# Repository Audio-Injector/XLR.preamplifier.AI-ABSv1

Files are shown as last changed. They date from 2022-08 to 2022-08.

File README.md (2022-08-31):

XLR preamplifier

A balanced preamplifier based on the Audio Injector Analogue Breakout Standard v1 (AI-ABS v1)

https://github.com/Audio-Injector/AudioInjector-Analogue-Breakout-Standard

https://www.audioinjector.net/xlr-preamp

https://shop.audioinjector.net/detail/Sound_Cards/Balanced+XLR+preamplifier

Check the single ended (RCA) preamplifier here : https://github.com/Audio-Injector/RCA.preamplifier.AI-ABSv1

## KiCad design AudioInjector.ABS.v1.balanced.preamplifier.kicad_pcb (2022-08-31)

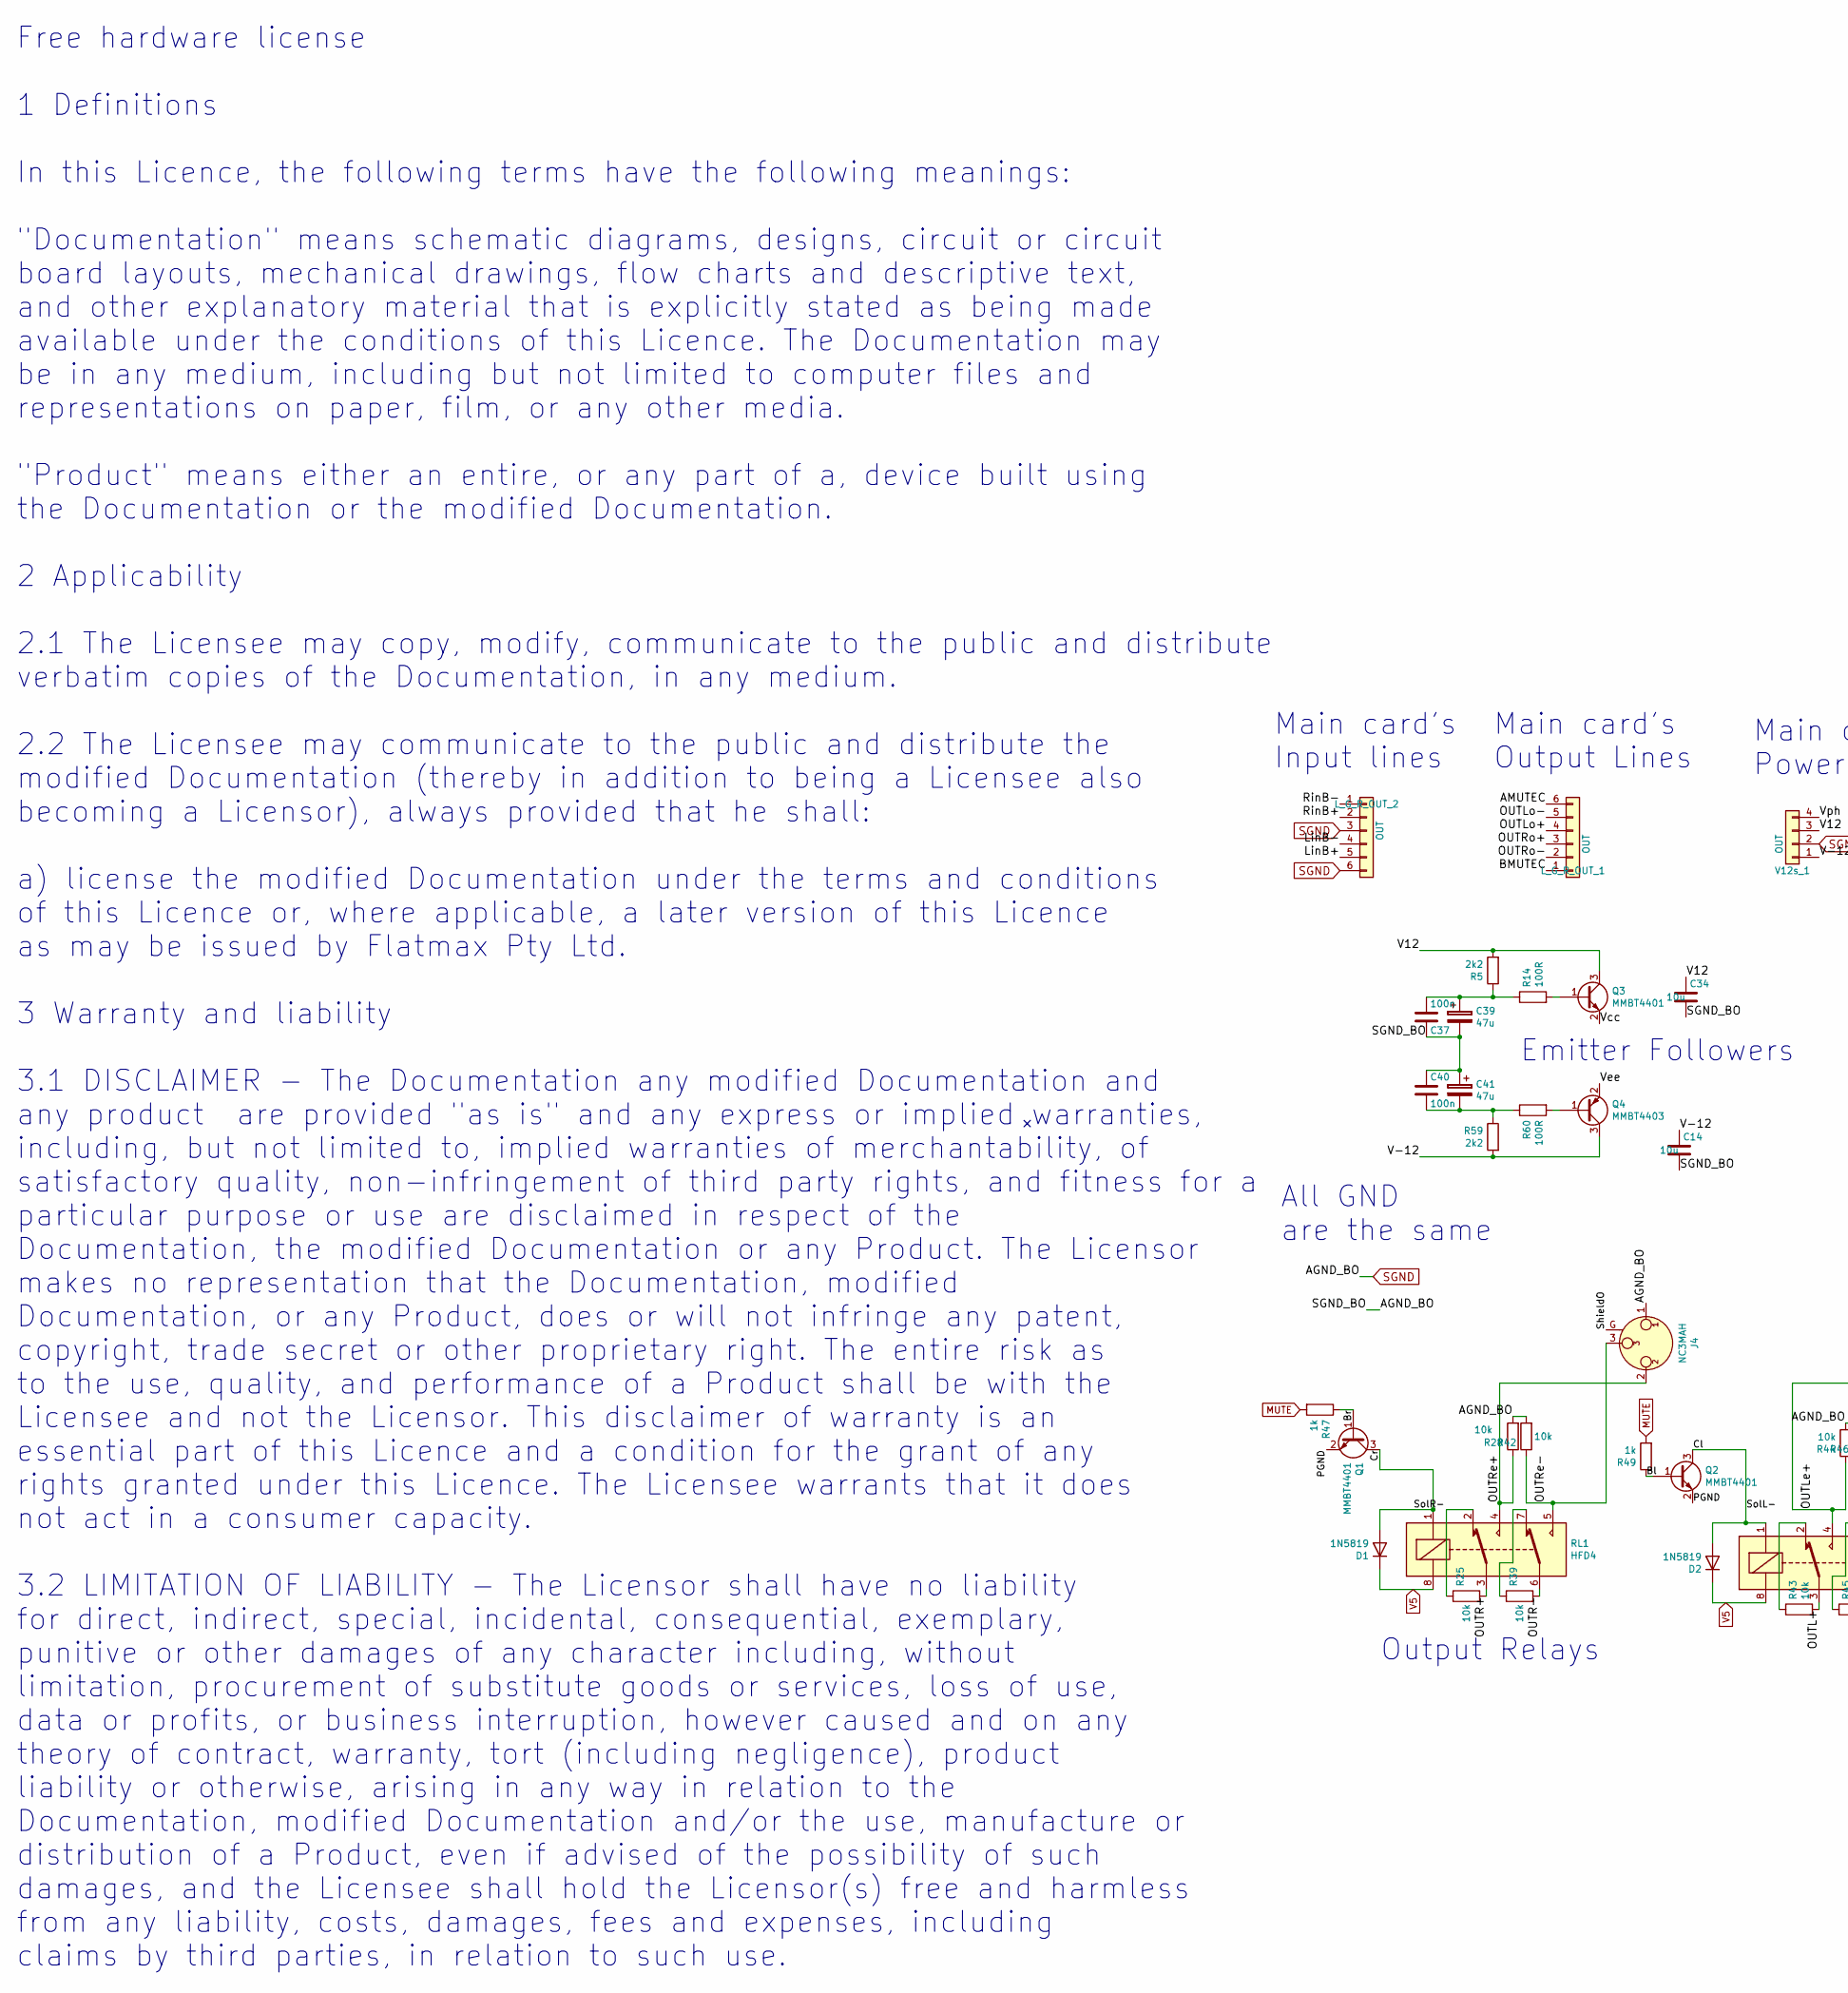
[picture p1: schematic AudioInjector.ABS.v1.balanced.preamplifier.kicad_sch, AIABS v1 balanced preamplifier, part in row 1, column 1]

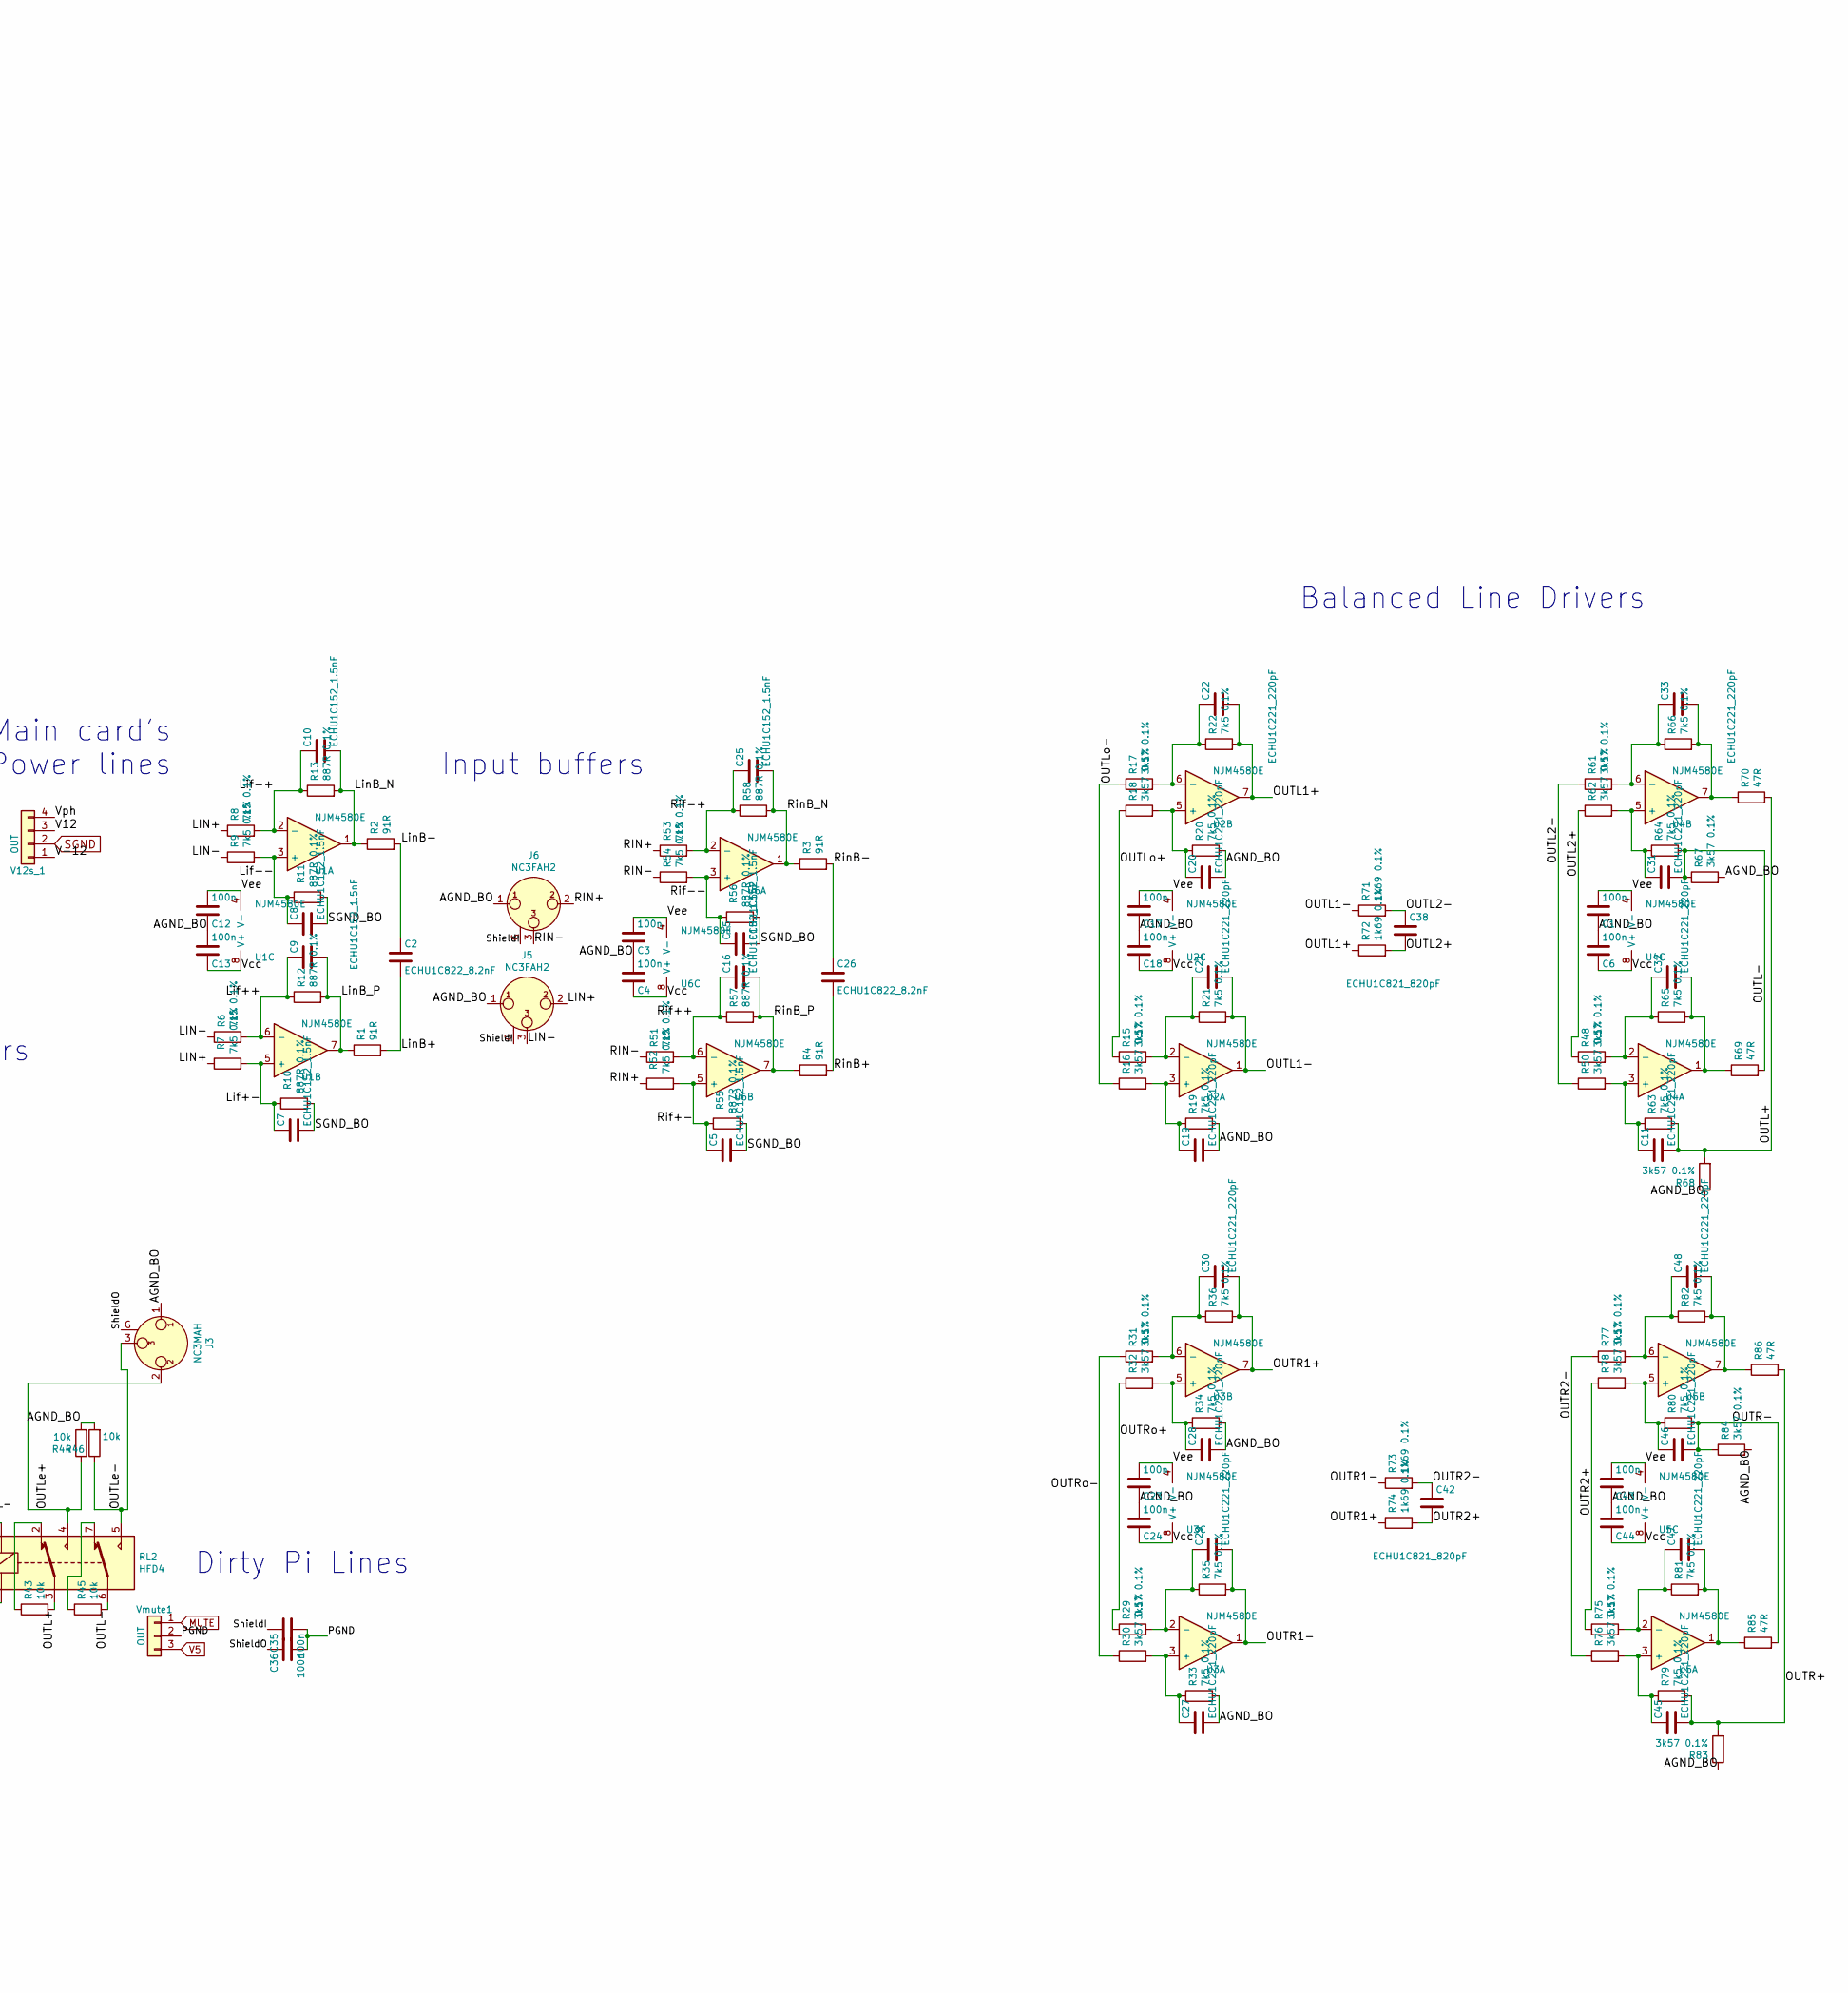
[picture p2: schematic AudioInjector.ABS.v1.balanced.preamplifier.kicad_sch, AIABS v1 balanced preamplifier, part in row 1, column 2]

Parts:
C1, C3, C4, C6, C12, C13, C17, C18, C23, C24, C35, C36, C37, C40, C43, C44: 100n; C_0603_1608Metric
C2, C26: ECHU1C822_8.2nF; C_0805_2012Metric
C5, C7, C8, C9, C10, C15, C16, C25: ECHU1C152_1.5nF; C_0805_2012Metric
C11, C19, C20, C21, C22, C27, C28, C29, C30, C31, C32, C33, C45, C46, C47, C48: ECHU1C221_220pF; C_0805_2012Metric
C14, C34: 10u; C_0805_2012Metric
C38, C42: ECHU1C821_820pF; C_0805_2012Metric
C39, C41: 47u; CP_Elec_6.3x7.7
D1, D2: 1N5819; D_SOD-123
J3, J4: NC3MAH; Jack_XLR_Neutrik_NC3MAH-0_Horizontal
J5, J6: NC3FAH2; Jack_XLR_Neutrik_NC3FAH2_Horizontal
L_G_R_OUT_1, L_G_R_OUT_2: OUT; PinHeader_1x06_P2.54mm_Vertical
Q1, Q2, Q3: MMBT4401; SOT-23
Q4: MMBT4403; SOT-23
R1, R2, R3, R4: 91R; R_0603_1608Metric
R5, R59: 2k2; R_0603_1608Metric
R6, R7, R8, R9, R19, R20, R21, R22, R33, R34, R35, R36, R51, R52, R53, R54, R63, R64, R65, R66, R79, R80, R81, R82: 7k5 0.1%; R_0603_1608Metric
R10, R11, R12, R13, R55, R56, R57, R58: 887R 0.1%; R_0603_1608Metric
R14, R60: 100R; R_0603_1608Metric
R15, R16, R17, R18, R29, R30, R31, R32, R48, R50, R61, R62, R67, R68, R75, R76, R77, R78, R83, R84: 3k57 0.1%; R_0603_1608Metric
R25, R28, R39, R42, R43, R44, R45, R46: 10k; R_0603_1608Metric
R47, R49: 1k; R_0603_1608Metric
R69, R70, R85, R86: 47R; R_0603_1608Metric
R71, R72, R73, R74: 1k69 0.1%; R_0603_1608Metric
RL1, RL2: HFD4; HDF4
U1, U2, U3, U4, U5, U6: NJM4580E; SOIC-8_3.9x4.9mm_P1.27mm
V12s_1: OUT; PinHeader_1x04_P2.54mm_Vertical
Vmute1: OUT; PinHeader_1x03_P2.54mm_Vertical

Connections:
/AMUTEC: L_G_R_OUT_1.6
/BMUTEC: L_G_R_OUT_1.1
/Bl: Q2.1 (B), R49.1
/Br: Q1.1 (B), R47.1
/Cl: D2.2 (A), Q2.3 (C), RL2.1
/Cr: D1.2 (A), Q1.3 (C), RL1.1
/LIN+: J5.2, R7.1, R8.1
/LIN-: J5.3, R6.1, R9.1
/Lif++: C9.1, R6.2, R12.1, U1.6 (-)
/Lif+-: C7.1, R7.2, R10.1, U1.5 (+)
/Lif-+: C10.1, R8.2, R13.1, U1.2 (-)
/Lif--: C8.1, R9.2, R11.1, U1.3 (+)
/LinB+: C2.2, L_G_R_OUT_2.5, R1.2
/LinB-: C2.1, L_G_R_OUT_2.4, R2.2
/LinB_N: C10.2, R2.1, R13.2, U1.1
/LinB_P: C9.2, R1.1, R12.2, U1.7
/OUTL1+: C22.2, R22.2, R72.1, U2.7
/OUTL1-: C21.2, R21.2, R71.1, U2.1
/OUTL2+: C38.2, R48.1, R62.1, R72.2
/OUTL2-: C38.1, R50.1, R61.1, R71.2
/OUTL+: C11.2, R43.2, R63.2, R68.2, R70.2, RL2.3
/OUTL-: C31.2, R45.2, R64.2, R67.1, R69.2, RL2.6
/OUTLe+: J3.2, R44.1, RL2.4
/OUTLe-: J3.3, R46.1, RL2.5
/OUTLo+: L_G_R_OUT_1.4, R15.1, R18.1
/OUTLo-: L_G_R_OUT_1.5, R16.1, R17.1
/OUTR1+: C30.2, R36.2, R74.1, U3.7
/OUTR1-: C29.2, R35.2, R73.1, U3.1
/OUTR2+: C42.2, R74.2, R75.1, R78.1
/OUTR2-: C42.1, R73.2, R76.1, R77.1
/OUTR+: C45.2, R25.2, R79.2, R83.2, R86.2, RL1.3
/OUTR-: C46.2, R39.2, R80.2, R84.1, R85.2, RL1.6
/OUTRe+: J4.2, R28.1, RL1.4
/OUTRe-: J4.3, R42.1, RL1.5
/OUTRo+: L_G_R_OUT_1.3, R29.1, R32.1
/OUTRo-: L_G_R_OUT_1.2, R30.1, R31.1
/PGND: C35.2, C36.2, Q1.2 (E), Q2.2 (E), Vmute1.2
/RIN+: J6.2, R52.1, R53.1
/RIN-: J6.3, R51.1, R54.1
/Rif++: C16.1, R51.2, R57.1, U6.6 (-)
/Rif+-: C5.1, R52.2, R55.1, U6.5 (+)
/Rif-+: C25.1, R53.2, R58.1, U6.2 (-)
/Rif--: C15.1, R54.2, R56.1, U6.3 (+)
/RinB+: C26.2, L_G_R_OUT_2.2, R4.2
/RinB-: C26.1, L_G_R_OUT_2.1, R3.2
/RinB_N: C25.2, R3.1, R58.2, U6.1
/RinB_P: C16.2, R4.1, R57.2, U6.7
/ShieldI: C35.1, J5.G, J6.G
/ShieldO: C36.1, J3.G, J4.G
/V12: C34.1, Q3.3 (C), R5.2, V12s_1.3
/V-12: C14.1, Q4.3 (C), R59.2, V12s_1.1
/Vcc: C4.1, C6.1, C13.1, C18.1, C24.1, C44.1, Q3.2 (E), U1.8 (V+), U2.8 (V+), U3.8 (V+), U4.8 (V+), U5.8 (V+), U6.8 (V+)
/Vee: C1.2, C3.2, C12.2, C17.2, C23.2, C43.2, Q4.2 (E), U1.4 (V-), U2.4 (V-), U3.4 (V-), U4.4 (V-), U5.4 (V-), U6.4 (V-)
/Vph: V12s_1.4
MUTE: R47.2, R49.2, Vmute1.1
unnamed: C11.1, R50.2, R63.1, U4.3 (+)
unnamed: C19.1, R16.2, R19.1, U2.3 (+)
unnamed: C20.1, R18.2, R20.1, U2.5 (+)
unnamed: C21.1, R15.2, R21.1, U2.2 (-)
unnamed: C22.1, R17.2, R22.1, U2.6 (-)
unnamed: C27.1, R30.2, R33.1, U3.3 (+)
unnamed: C28.1, R32.2, R34.1, U3.5 (+)
unnamed: C29.1, R29.2, R35.1, U3.2 (-)
unnamed: C30.1, R31.2, R36.1, U3.6 (-)
unnamed: C31.1, R62.2, R64.1, U4.5 (+)
unnamed: C32.1, R48.2, R65.1, U4.2 (-)
unnamed: C32.2, R65.2, R69.1, U4.1
unnamed: C33.1, R61.2, R66.1, U4.6 (-)
unnamed: C33.2, R66.2, R70.1, U4.7
unnamed: C37.2, C39.1, R5.1, R14.1
unnamed: C40.2, C41.2, R59.1, R60.1
unnamed: C45.1, R76.2, R79.1, U5.3 (+)
unnamed: C46.1, R78.2, R80.1, U5.5 (+)
unnamed: C47.1, R75.2, R81.1, U5.2 (-)
unnamed: C47.2, R81.2, R85.1, U5.1
unnamed: C48.1, R77.2, R82.1, U5.6 (-)
unnamed: C48.2, R82.2, R86.1, U5.7
unnamed: Q3.1 (B), R14.2
unnamed: Q4.1 (B), R60.2
unnamed: R25.1, RL1.2
unnamed: R39.1, RL1.7
unnamed: R43.1, RL2.2
unnamed: R45.1, RL2.7
SGND: C1.1, C3.1, C4.2, C5.2, C6.2, C7.2, C8.2, C12.1, C13.2, C14.2, C15.2, C17.1, C18.2, C19.2, C20.2, C23.1, C24.2, C27.2, C28.2, C34.2, C37.1, C39.2, C40.1, C41.1, C43.1, C44.2, J3.1, J4.1, J5.1, J6.1, L_G_R_OUT_2.3, L_G_R_OUT_2.6, R10.2, R11.2, R19.2, R20.2, R28.2, R33.2, R34.2, R42.2, R44.2, R46.2, R55.2, R56.2, R67.2, R68.1, R83.1, R84.2, V12s_1.2
V5: D1.1 (K), D2.1 (K), RL1.8, RL2.8, Vmute1.3

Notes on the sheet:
All GND are the same
Input buffers
Free hardware license 1 Definitions In this Licence, the following terms have the following meanings: "Documentation" means schematic diagrams, designs, circuit or circuit board layouts, mechanical drawings, flow charts and descriptive text, and other explanatory material that is explicitly stated 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
Output Relays
Dirty Pi Lines
Main card's Output Lines
Main card's Input lines
Balanced Line Drivers
Main card's Power lines
Emitter Followers

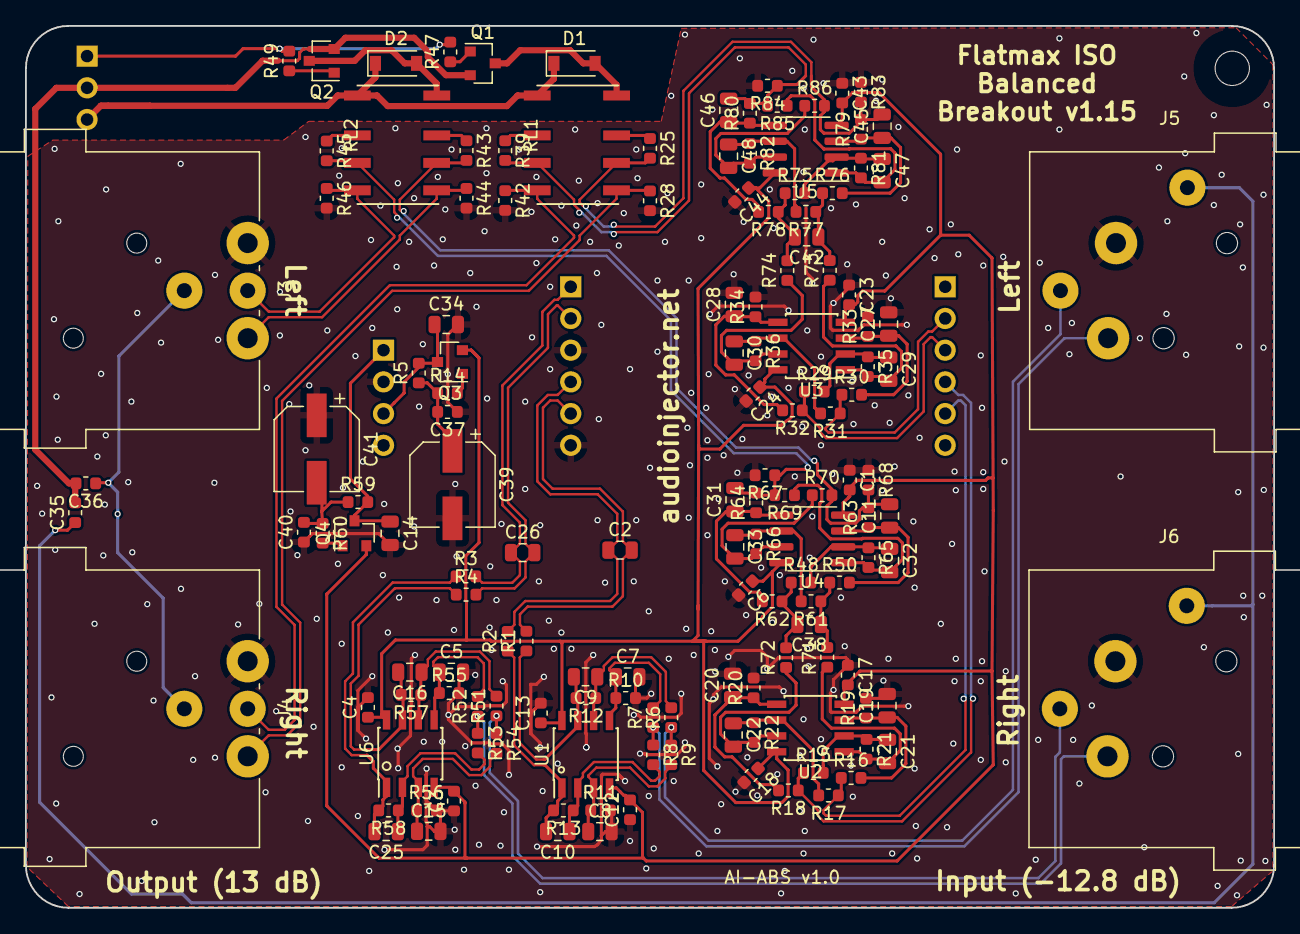
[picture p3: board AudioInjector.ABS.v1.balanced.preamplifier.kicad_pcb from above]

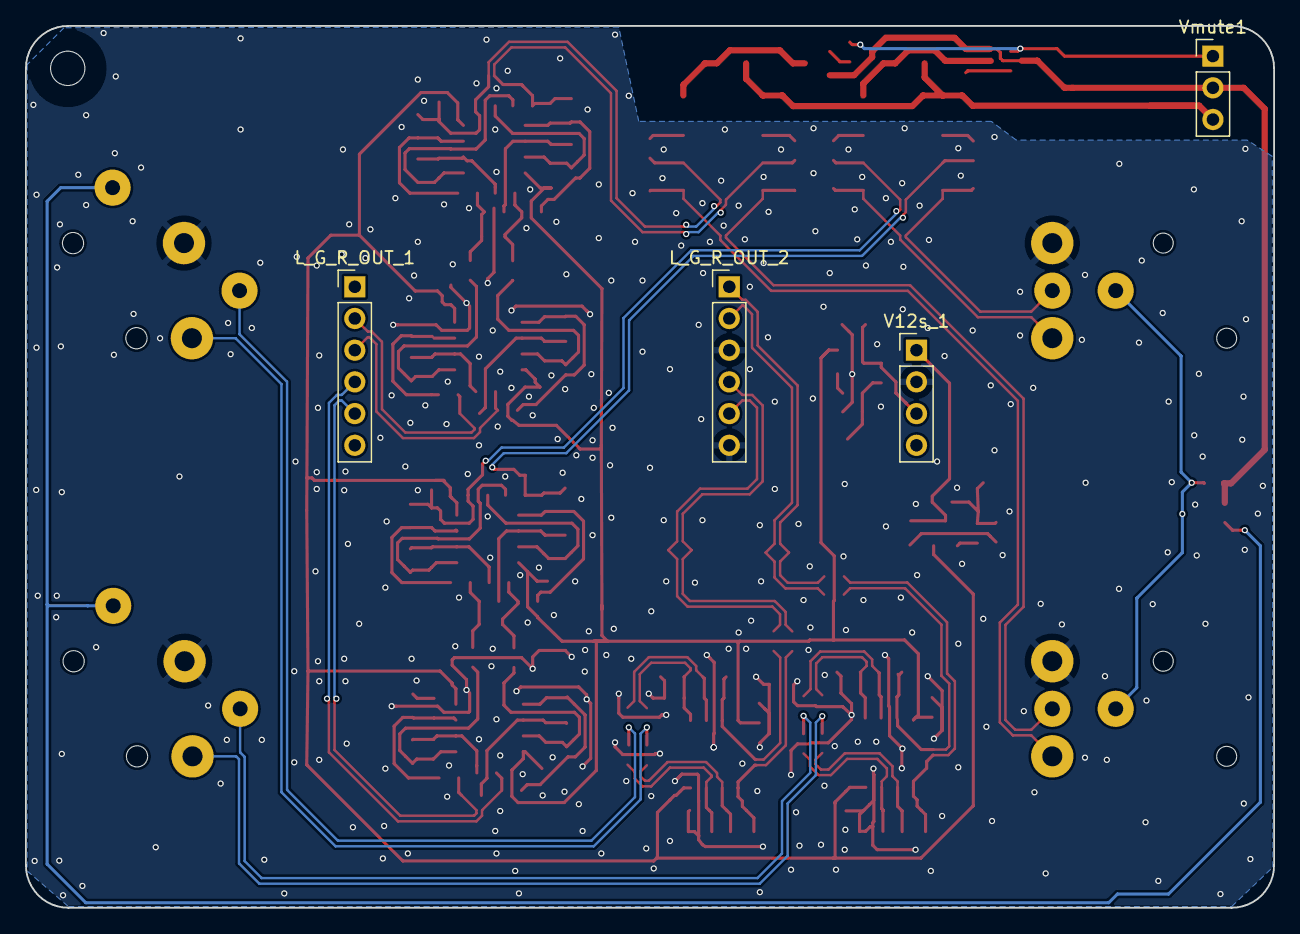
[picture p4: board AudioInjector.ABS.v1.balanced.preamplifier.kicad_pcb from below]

Board: 4 copper layers, 100.0 x 70.7 mm, 148 parts (4 on the bottom side), 82 nets.

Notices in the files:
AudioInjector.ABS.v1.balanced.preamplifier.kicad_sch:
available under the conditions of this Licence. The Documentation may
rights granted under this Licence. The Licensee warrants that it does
